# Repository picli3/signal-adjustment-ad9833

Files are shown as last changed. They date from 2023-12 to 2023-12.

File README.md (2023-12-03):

# Ajustador de señal DDS (AD9833)
El modulo AD9833 es capaz de general señales para ser usadas para diversas aplicaciones, sin embargo, esta señal siempre es continua, es por esta razon que implemente este circuito, el cual consistene en llevar la señal a valores negativos, ademas de aumentar la ganancia de la señal de salida.

## Diagrama de bloques



El bloque de **POWER** esta porque con eso se genera un voltage negativo de **-5V** para el amplificador operacional, en este caso el **LM358**

## PCB
Todo el circuito esta en una cara asi que sera facil soldar.



Los archivos de fabricacion los puedes descargar [aqui](https://github.com/picli3/signal-adjustment-ad9833/releases/download/v1.0.0/v1.0.0.zip)

Mas información [maykolrey.com](https://maykolrey.com)
[licencia](./LICENSE)

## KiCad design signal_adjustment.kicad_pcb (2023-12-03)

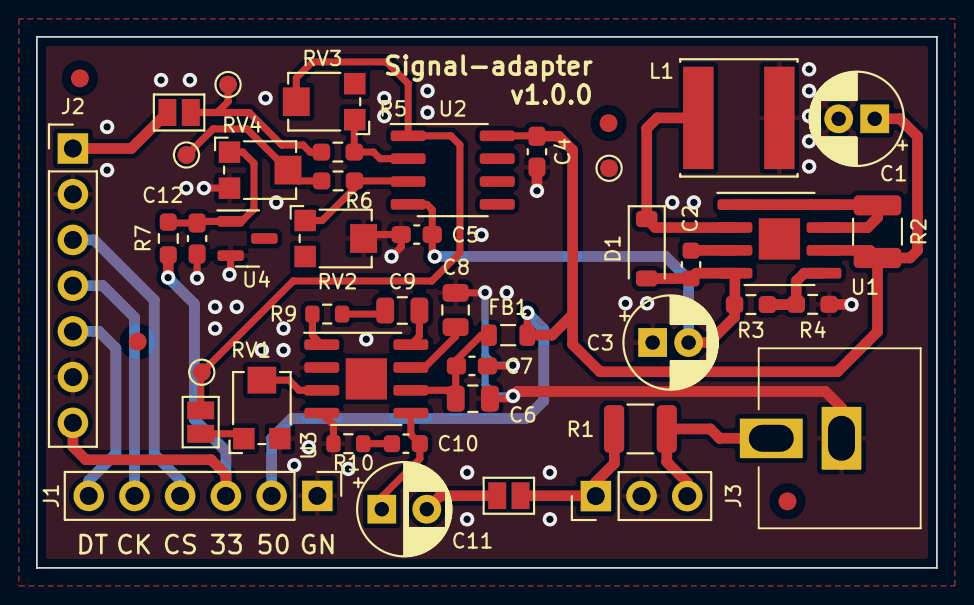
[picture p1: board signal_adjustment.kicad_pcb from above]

Board: 2 copper layers, 50.0 x 29.5 mm, 47 parts (0 on the bottom side), 30 nets.

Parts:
C1, C3: 100u; CP_Radial_D5.0mm_P2.00mm
C2: 1n; C_0603_1608Metric
C4, C5, C7, C12: 100nF; C_0603_1608Metric_Pad1.08x0.95mm_HandSolder
C6, C8, C9: 10uF; C_0805_2012Metric
C10: 47nF; C_0603_1608Metric
C11: 220uF; CP_Radial_D5.0mm_P2.50mm
D1: 1N5819; D_SOD-123
FB1: 120@100MHz; L_0805_2012Metric
FID1, FID2, FID3, FID4: Fiducial; Fiducial_1mm_Mask2mm
J1: Conn_01x06; PinHeader_1x06_P2.54mm_Vertical
J2: AD9833; PinHeader_1x07_P2.54mm_Vertical
J3: Conn_01x03; PinHeader_1x03_P2.54mm_Vertical
J4: Conn_Coaxial; RCA-Av-8.4-5
JP1, JP2, JP3: Jumper_2_Open; SolderJumper-2_P1.3mm_Open_Pad1.0x1.5mm
L1: 100u; L_Changjiang_FNR6045S
R1: 2; R_1210_3225Metric
R2: 0.22; R_1210_3225Metric
R3, R7: 1k; R_0603_1608Metric_Pad0.98x0.95mm_HandSolder
R4: 3k; R_0603_1608Metric_Pad0.98x0.95mm_HandSolder
R5, R6: 10k; R_0603_1608Metric_Pad0.98x0.95mm_HandSolder
R9: 1.2k; R_0603_1608Metric
R10: 10; R_0603_1608Metric
RV1: 10k; Potentiometer_Bourns_TC33X_Vertical
RV2, RV3: 50k; Potentiometer_Bourns_TC33X_Vertical
RV4: 1k; Potentiometer_Bourns_TC33X_Vertical
TP1: VREF; TestPoint_Pad_D1.0mm
TP2: VIN; TestPoint_Pad_D1.0mm
TP3: VOUT; TestPoint_Pad_D1.0mm
TP4: GND; TestPoint_Pad_D1.0mm
U1: MC34063; HSOP-8-1EP_3.9x4.9mm_P1.27mm_EP2.3x2.3mm
U2: LM358; SOIC-8_3.9x4.9mm_P1.27mm
U3: LM386; HSOP-8-1EP_3.9x4.9mm_P1.27mm_EP2.3x2.3mm
U4: ADR510; SOT-23

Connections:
+3V3: J1.3, J2.7, R7.2
+5V: C1.1, C4.1, FB1.2, J1.2, R2.1, U1.6 (Vin), U2.8 (V+)
/Amplifier/INPUT: JP2.2 (B), RV1.1
/Amplifier/OUTPUT: C11.2, JP3.1 (A)
/SCLK: J1.5, J2.4
/SDATA: J1.6, J2.5
/S_OUT: J2.1, JP1.1 (A)
/leveling/-5V: C2.2, C3.2, C5.2, D1.2 (A), R3.2, U1.4 (GND), U2.4 (V-)
/leveling/SIGNAL_IN: JP1.2 (B), R5.2, TP2.1
/leveling/SIGNAL_OUT: JP2.1 (A), RV3.2, TP3.1, U2.1
/power/ref: R3.1, R4.1, U1.5 (Vfb)
/~CS: J1.4, J2.3
GND: C1.2, C3.1, C4.2, C5.1, C6.1, C7.1, C8.2, C12.2, J1.1, J2.2, J2.6, J3.2, J4.2 (Ext), L1.2, R4.2, R10.1, RV1.3, RV2.2, RV4.3, TP4.1, U3.2 (-), U3.4 (GND), U4.2
unnamed: C9.1, U3.8 (GAIN)
unnamed: C9.2, R9.1
unnamed: C10.1, R10.2
unnamed: C10.2, C11.1, U3.5
unnamed: C12.1, R7.1, RV4.1, U4.1
unnamed: D1.1 (K), L1.1, U1.2 (SwE)
unnamed: J3.1, JP3.2 (B), R1.1
unnamed: J3.3, J4.1 (In), R1.2
unnamed: R6.2, RV4.2, TP1.1
unnamed: R9.2, U3.1 (GAIN)
unnamed: R2.2, U1.1 (SwC), U1.7 (Ipk), U1.8 (DC)
unnamed: C2.1, U1.3 (TC)
unnamed: R6.1, RV2.1, U2.3 (+)
unnamed: R5.1, RV3.1, U2.2 (-)
unnamed: RV1.2, U3.3 (+)
unnamed: C8.1, U3.7 (BYPASS)
unnamed: C6.2, C7.2, FB1.1, U3.6 (V+)

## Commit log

2023-12-03 agregando primera interaccion
    [amplifier.kicad_sch, leveling.kicad_sch, power_5v.kicad_sch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]
2023-12-03 primera version
    [power_5v.kicad_sch, signal_adjustment.kicad_pcb, signal_adjustment.kicad_sch]
